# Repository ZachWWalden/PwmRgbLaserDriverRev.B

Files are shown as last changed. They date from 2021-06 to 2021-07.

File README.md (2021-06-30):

# PwmRgbLaserDriverRev.B
This repository contains the Kicad files for a PCB that drives a 3 segment full color laser assembly that has an adjustable white point. It can be modulated with either Pulse-Width Modulation with a 5V digital signal at each segments input terminal. It may also be modulated using a simple analog voltage at each input terminal.

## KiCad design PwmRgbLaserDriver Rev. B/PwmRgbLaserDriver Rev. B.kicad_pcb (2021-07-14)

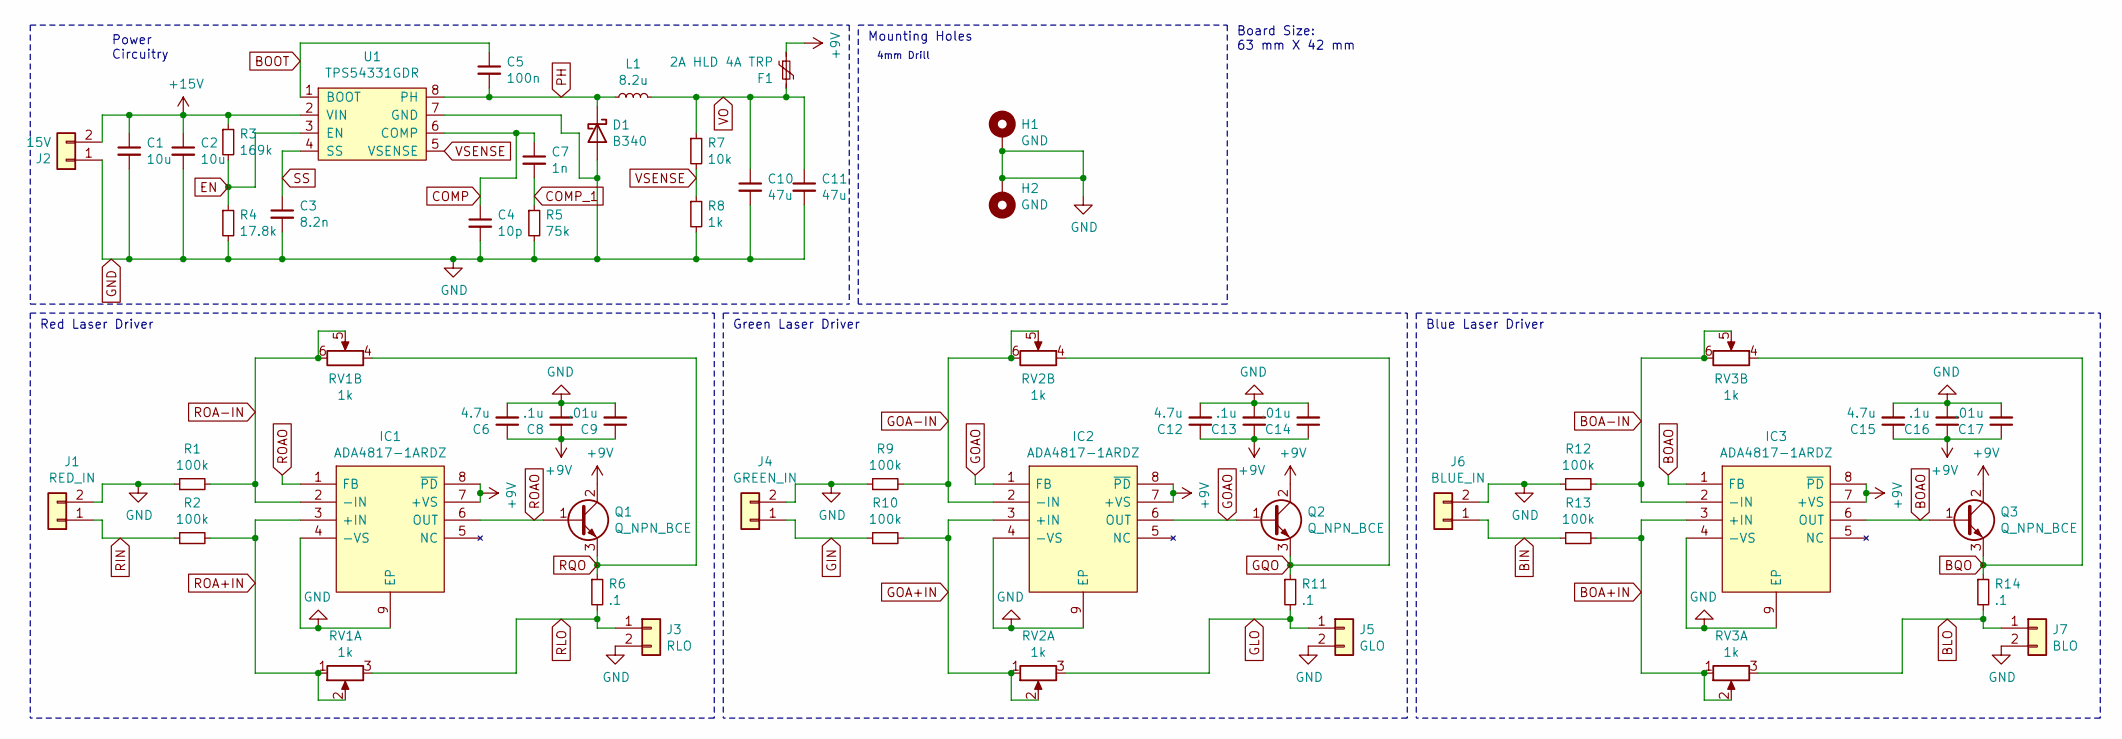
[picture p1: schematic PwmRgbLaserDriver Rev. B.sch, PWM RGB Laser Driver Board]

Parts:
C1, C2: 10u; C_0805_2012Metric_Pad1.18x1.45mm_HandSolder
C3: 8.2n; C_0402_1005Metric_Pad0.74x0.62mm_HandSolder
C4: 10p; C_0402_1005Metric_Pad0.74x0.62mm_HandSolder
C5: 100n; C_0402_1005Metric_Pad0.74x0.62mm_HandSolder
C6, C12, C15: 4.7u; C_0805_2012Metric_Pad1.18x1.45mm_HandSolder
C7: 1n; C_0402_1005Metric_Pad0.74x0.62mm_HandSolder
C8, C13, C16: .1u; C_0402_1005Metric_Pad0.74x0.62mm_HandSolder
C9, C14, C17: .01u; C_0402_1005Metric_Pad0.74x0.62mm_HandSolder
C10, C11: 47u; C_1210_3225Metric_Pad1.33x2.70mm_HandSolder
D1: B340; D_SMA_Handsoldering
F1: 2A HLD 4A TRP; Fuse_2920_7451Metric_Pad2.10x5.45mm_HandSolder
H1, H2: GND; 4mm Mounting Hole
IC1, IC2, IC3: ADA4817-1ARDZ; SOIC127P600X175-9N; Mouser Part Number 584-ADA4817-1ARDZ
J1: RED_IN; PinHeader_1x02_P2.54mm_Vertical
J2: 15V; PinHeader_1x02_P2.54mm_Vertical
J3: RLO; PinHeader_1x02_P2.54mm_Vertical
J4: GREEN_IN; PinHeader_1x02_P2.54mm_Vertical
J5: GLO; PinHeader_1x02_P2.54mm_Vertical
J6: BLUE_IN; PinHeader_1x02_P2.54mm_Vertical
J7: BLO; PinHeader_1x02_P2.54mm_Vertical
L1: 8.2u; Bourns SRP6540
Q1, Q2, Q3: Q_NPN_BCE; SOT-89-3_Handsoldering
R1, R2, R9, R10, R12, R13: 100k; R_0402_1005Metric_Pad0.72x0.64mm_HandSolder
R3: 169k; R_0402_1005Metric_Pad0.72x0.64mm_HandSolder
R4: 17.8k; R_0402_1005Metric_Pad0.72x0.64mm_HandSolder
R5: 75k; R_0402_1005Metric_Pad0.72x0.64mm_HandSolder
R6, R11, R14: .1; R_0402_1005Metric_Pad0.72x0.64mm_HandSolder
R7: 10k; R_0805_2012Metric_Pad1.20x1.40mm_HandSolder
R8: 1k; R_0603_1608Metric_Pad0.98x0.95mm_HandSolder
RV1, RV2, RV3: 1k; DualGangPotAmazon
U1: TPS54331GDR; SOIC-8_3.9x4.9mm_P1.27mm

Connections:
+9V: C6.1, C8.1, C9.1, C12.1, C13.1, C14.1, C15.1, C16.1, C17.1, F1.1, IC1.7 (+VS), IC1.8 (~PD), IC2.7 (+VS), IC2.8 (~PD), IC3.7 (+VS), IC3.8 (~PD), Q1.2 (C), Q2.2 (C), Q3.2 (C)
+15V: C1.1, C2.1, J2.2, R3.1, U1.2 (VIN)
BIN: J6.1, R13.1
BLO: J7.1, R14.2, RV3.3
BOA+IN: IC3.3 (+IN), R13.2, RV3.1, RV3.2
BOA-IN: IC3.2 (-IN), R12.2, RV3.5, RV3.6
BOAO: IC3.1 (FB), IC3.6 (OUT), Q3.1 (B)
BOOT: C5.1, U1.1 (BOOT)
BQO: Q3.3 (E), R14.1, RV3.4
COMP: C4.1, C7.1, U1.6 (COMP)
COMP_1: C7.2, R5.1
EN: R3.2, R4.1, U1.3 (EN)
GIN: J4.1, R10.1
GLO: J5.1, R11.2, RV2.3
GND: C1.2, C2.2, C3.2, C4.2, C6.2, C8.2, C9.2, C10.2, C11.2, C12.2, C13.2, C14.2, C15.2, C16.2, C17.2, D1.2 (A), H1.1, H2.1, IC1.4 (-VS), IC1.9 (EP), IC2.4 (-VS), IC2.9 (EP), IC3.4 (-VS), IC3.9 (EP), J1.2, J2.1, J3.2, J4.2, J5.2, J6.2, J7.2, R1.1, R4.2, R5.2, R8.2, R9.1, R12.1, U1.7 (GND)
GOA+IN: IC2.3 (+IN), R10.2, RV2.1, RV2.2
GOA-IN: IC2.2 (-IN), R9.2, RV2.5, RV2.6
GOAO: IC2.1 (FB), IC2.6 (OUT), Q2.1 (B)
GQO: Q2.3 (E), R11.1, RV2.4
PH: C5.2, D1.1 (K), L1.1, U1.8 (PH)
RIN: J1.1, R2.1
RLO: J3.1, R6.2, RV1.3
ROA+IN: IC1.3 (+IN), R2.2, RV1.1, RV1.2
ROA-IN: IC1.2 (-IN), R1.2, RV1.5, RV1.6
ROAO: IC1.1 (FB), IC1.6 (OUT), Q1.1 (B)
RQO: Q1.3 (E), R6.1, RV1.4
SS: C3.1, U1.4 (SS)
VO: C10.1, C11.1, F1.2, L1.2, R7.1
VSENSE: R7.2, R8.1, U1.5 (VSENSE)

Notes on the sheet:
Red Laser Driver
Green Laser Driver
Blue Laser Driver
Board Size: 63 mm X 42 mm
Power Circuitry
Mounting Holes
4mm Drill

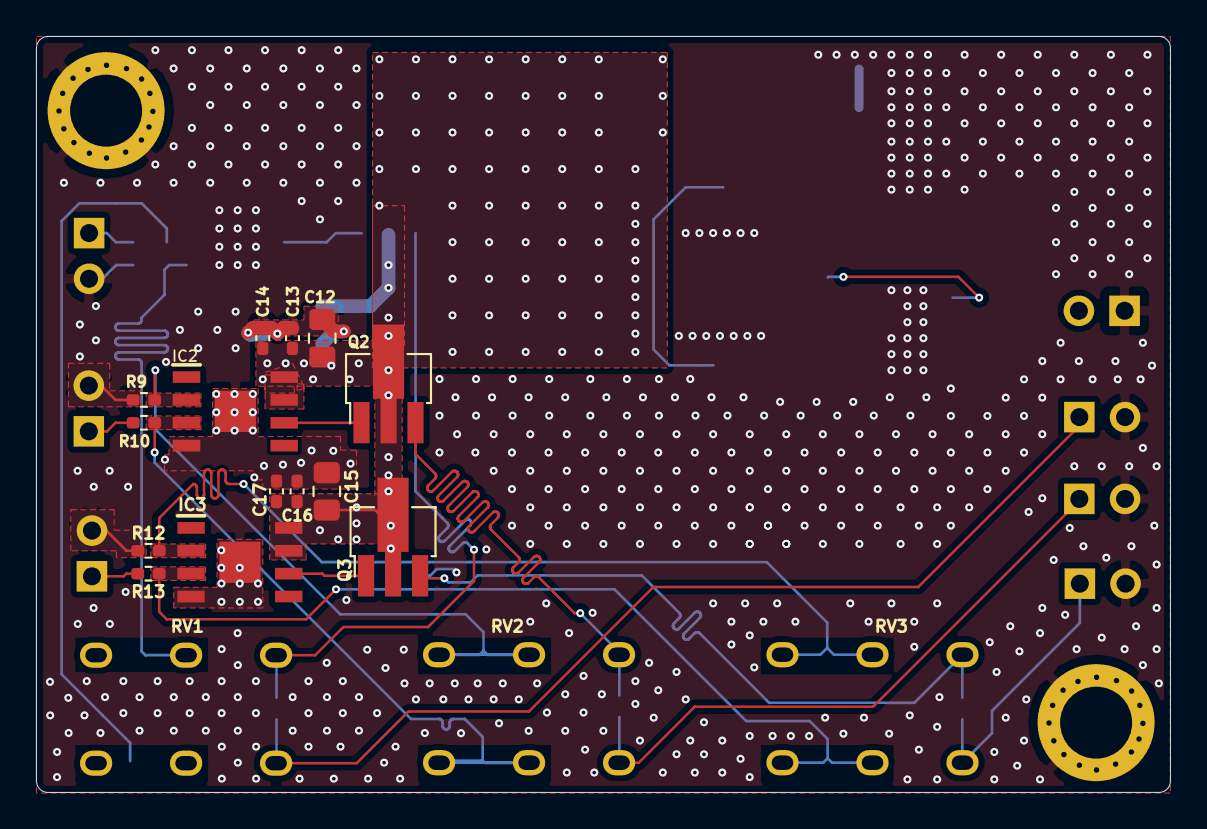
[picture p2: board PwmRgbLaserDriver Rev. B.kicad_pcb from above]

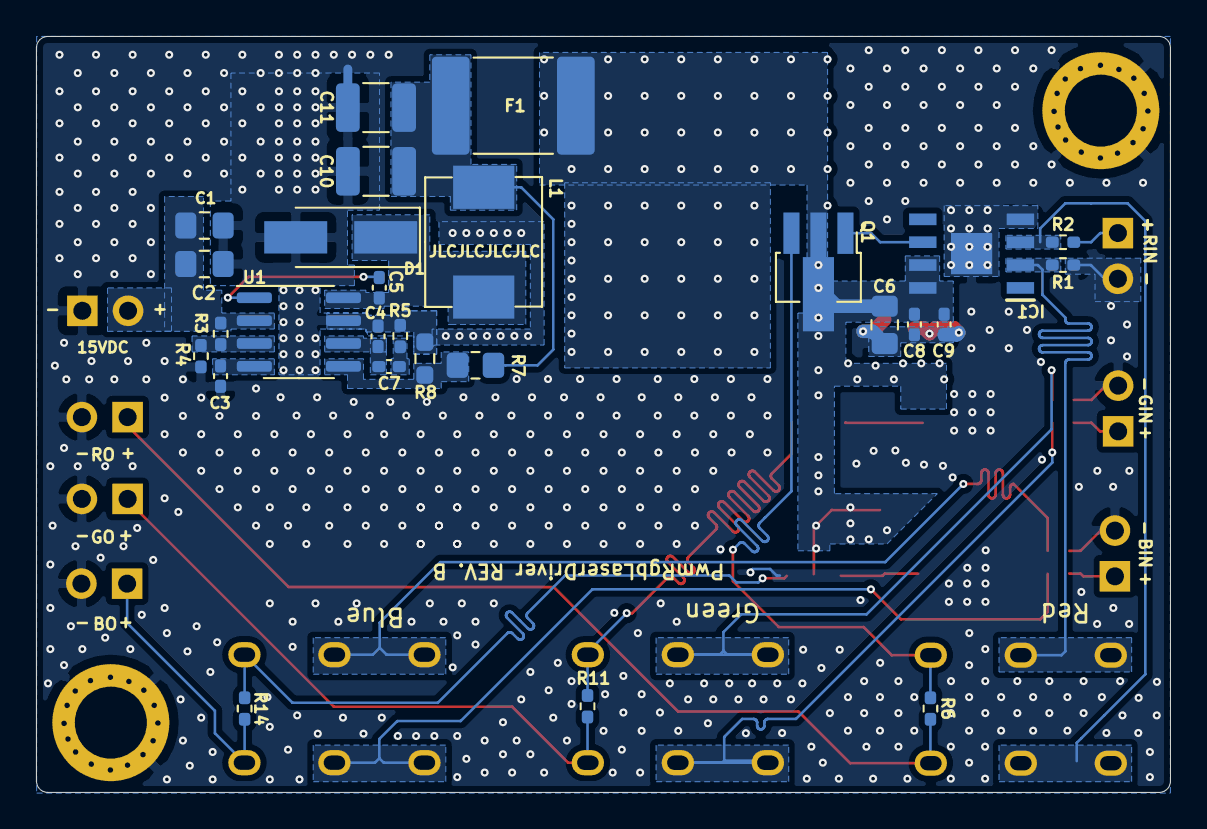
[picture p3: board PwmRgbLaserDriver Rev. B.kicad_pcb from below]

Board: 4 copper layers, 63.0 x 42.0 mm, 53 parts (27 on the bottom side), 29 nets.

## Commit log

2021-06-30 Current Source Schematic
    This commit contains the schematic for the constant current source for each laser diode.
    [PwmRgbLaserDriver Rev. B.kicad_pcb, PwmRgbLaserDriver Rev. B.sch]
2021-06-30 Switching Converter Added
    This commit adds the switching converter for power.
    [PwmRgbLaserDriver Rev. B.sch]
2021-06-30 Small Fixes
    Added Enable pin resistor divider on switcher. Fixed grounding issues in drivers
    [PwmRgbLaserDriver Rev. B.sch]
2021-06-30 TO-DO Update
    [PwmRgbLaserDriver Rev. B.sch]
2021-07-01 Fixed Some Errors
    Fixed some errors and updated the to-do list.
    [PwmRgbLaserDriver Rev. B.sch]
2021-07-01 Some Footprints Added
    [PwmRgbLaserDriver Rev. B.sch]
2021-07-02 Footprints, SMPS Placement
    Footprints have now been fully assigned.
    The components for the 27W SMPS have been placed.
    [PwmRgbLaserDriver Rev. B.kicad_pcb, PwmRgbLaserDriver Rev. B.sch]
2021-07-09 Placement And Some Routhing
    Placed all components and routed the important analog signal traces.
    Power remains unfinished along with precise placement of the mounting holes.
    [PwmRgbLaserDriver Rev. B.kicad_pcb, PwmRgbLaserDriver Rev. B.sch]
2021-07-10 Small Update
    Nothing Much
    [PwmRgbLaserDriver Rev. B.kicad_pcb]
2021-07-13 PDN Additions
    All copper pours have been placed. Some PDN stitching vias have been placed.
    [PwmRgbLaserDriver Rev. B.kicad_pcb]
2021-07-13 PDN & Silk Screen Improvements
    Small additions
    [PwmRgbLaserDriver Rev. B.kicad_pcb]
2021-07-14 Board Finished
    Board has been completed. PDN finished, Silk Screen cleaned up.
    [PwmRgbLaserDriver Rev. B-B_Cu.gbr, PwmRgbLaserDriver Rev. B-B_Mask.gbr, PwmRgbLaserDriver Rev. B-B_SilkS.gbr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]
